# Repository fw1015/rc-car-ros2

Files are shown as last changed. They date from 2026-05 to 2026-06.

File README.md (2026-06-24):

# RC Car ROS2 Project

An autonomous RC car built with **ROS 2 Jazzy**, **Raspberry Pi 5**, and a web-based control interface.





## Features

- **Real-time Web Control** — Control steering and throttle via browser (phone-friendly)
- **Live Camera Streaming** — Stream video from Raspberry Pi Camera Module 3 Wide
- **Multi-Sensor System** — VL53L5CX (ToF) + dual HC-SR04 ultrasonic sensors
- **Field Mode** — Built-in WiFi hotspot for outdoor operation (no home router needed)
- **ROS2 Architecture** — Web Server Node, Brain Node, Sensors Node, Movement Node
- **3D Printed Mounts** — Custom fixtures for Pi, camera, and sensors

## Media & Demo

### Hardware Assembly
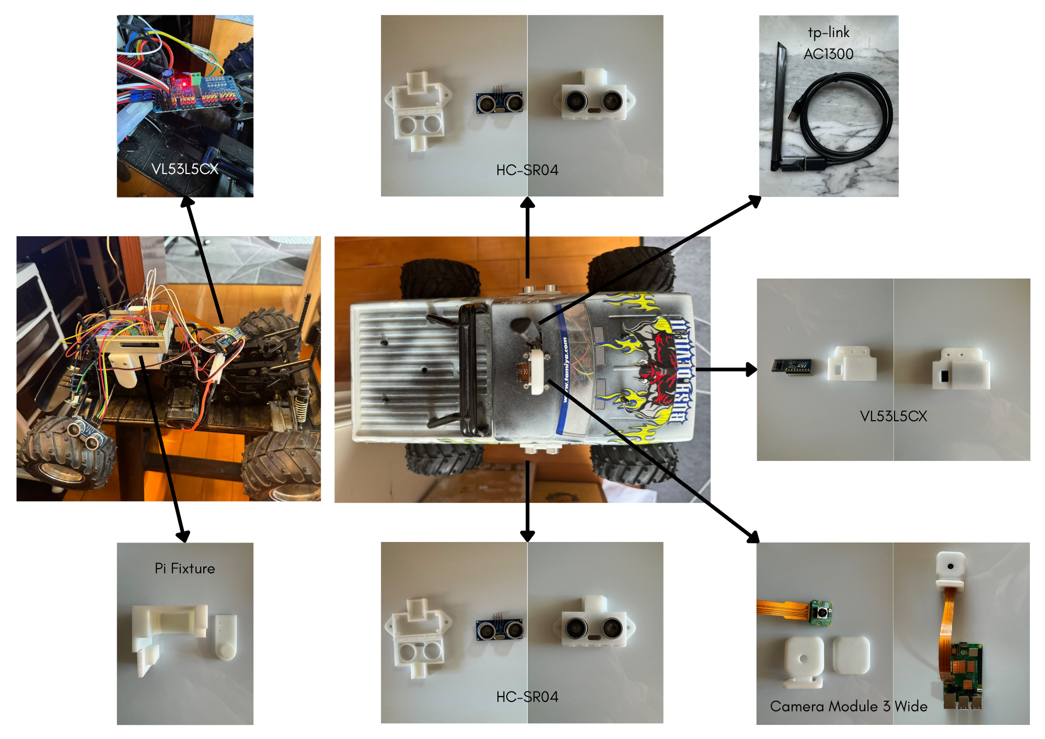
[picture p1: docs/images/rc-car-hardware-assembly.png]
RC Car Hardware Components


### Demo Video
Watch the RC car being controlled in real-time via the web interface:

[▶️ Watch Demo Video](https://github.com/fw1015/rc-car-ros2/releases/download/v1.0/RC.Control.mp4)

---

## Tech Stack

- **ROS 2 Jazzy** (Ubuntu 24.04)
- **Raspberry Pi 5** + Camera Module 3 Wide
- **Python** + Flask (web interface)
- **gpiozero** + LGPIO (hardware control)
- **SolidWorks** (3D design)

## Project Structure

```bash
rc-car-ros2/
├── src/
│   ├── web_interface/            # Flask web server + frontend
│   ├── robot_brain/              # Decision making & safety logic
│   ├── robot_movement/           # Servo and ESC control nodes
│   ├── robot_sensors/            # ToF + Ultrasonic sensor nodes
│   └── camera_ros/               # Camera streaming node
├── docs/
│   ├── images/                   # Hardware photos and diagrams
│   └── hardware_architecture.md  # Hardware mapping and pin connections
├── hardware/
│   └── 3d_models/                # STL files for 3D printed parts
├── .gitignore
└── README.md

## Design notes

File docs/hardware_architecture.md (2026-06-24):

# Hardware Architecture & Node Mapping

This document outlines the hardware components, their corresponding ROS 2 nodes, and the physical wiring architecture of the autonomous RC vehicle.

## Node Overview

| Node | Hardware? | Model | Placement | Publish | Subscribe | Message Type | Service/Client |
|---|---|---|---|---|---|---|---|
| `robot_brain_node` | N | NA | NA | `/cmd_vel` | `/tof/distance`, `/cmd_vel_raw` | `Twist`, `Float64` | Client to `i2c_manager` |
| `tof_sensor_node` | Y | VL53L5CX | Front | `/tof/distance` | - | `Float64` | - |
| `us_sensor_node (L)`  | Y | HC-SR04 | Left | `/left_distance` | - | `Range` | - |
| `us_sensor_node (R)`  | Y | HC-SR04 | Right | `/right_distance` | - | `Range` | - |
| `i2c_manager` | Y | PCA9685 + QUICRUN-1060 | Mid | - | - | - | Service (`set_esc`) |
| `web_server_node` | N | NA | NA | `/cmd_vel_raw` | `/tof/distance`, `/left_distance`, `/right_distance` | `Twist` | - |

---

## Hardware Components

### USB WiFi Adapter (TP-Link Archer T3U Plus)

- **Model**: TP-Link Archer T3U Plus (AC1300)
- **Purpose**: Provides stable, longer-range WiFi connectivity for outdoor operation and reliable live camera streaming.
- **Connection Type**: USB 3.0 (plugged into Raspberry Pi 5 USB port)
- **Usage**:
  - Acts as WiFi **client** when connecting to a phone hotspot in Field Mode.
  - Improves stability and range compared to the built-in Raspberry Pi WiFi, especially outdoors.
- **Power Consumption**: ~500–900mA under load (powered directly from Pi USB 3.0 port).
- **Notes**: 
  - Used primarily to maintain a stable connection for camera streaming when operating away from home WiFi.
  - Helps reduce latency and dropouts during outdoor testing.

### VL53L5CX (ToF Sensor)
- **PIN 1 (3V3 Power)**: LPn, PWREN, AVDD, IOVDD
- **PIN 3 (GPIO 2)**: SDA
- **PIN 5 (GPIO 3)**: SCL
- **PIN 9 (GND)**: GND

### HC-SR04 (Left Ultrasonic)
- **PIN 2 (5V Power)**: VCC
- **PIN 9 (GND)**: GND
- **PIN 13 (GPIO 27)**: Trig
- **PIN 15 (GPIO 22)**: Echo

### HC-SR04 (Right Ultrasonic)
- **PIN 4 (5V Power)**: VCC
- **PIN 9 (GND)**: GND
- **PIN 16 (GPIO 23)**: Trig
- **PIN 18 (GPIO 24)**: Echo

### PCA9685 (I2C Motor Manager)
- **PIN 17 (3V3 Power)**: VCC (logic)
- **PIN 34 & 39 (GND)**: GND + OE
- **Channel 0**: QUICRUN-1060 ESC (Throttle)
- **Channel 2**: Futaba S3003 Servo (Steering)

---

## Power Architecture

- **Main Battery (7.2V NiMH)**: Powers the ESC directly.
- **ESC Built-in BEC (6V/3A)**: Powers the PCA9685 V+ rail → Futaba S3003 steering servo.
- **Pi 5V Rail**: Powers the Raspberry Pi, **TP-Link Archer T3U Plus**, Camera Module 3, and both HC-SR04 sensors.
- **Pi 3.3V Rail**: Powers the VL53L5CX ToF sensor and PCA9685 logic (VCC).
- **Common Ground**: All components share a common ground to ensure signal integrity.

**Note on USB WiFi Adapter**: The TP-Link Archer T3U Plus draws power from the Pi’s USB 3.0 port. While the Pi 5 can generally handle it, high camera streaming load + USB WiFi may increase total current draw. Monitor thermals during long outdoor sessions.

---

## Notes

- HC-SR04 Echo pins use a voltage divider (1kΩ + 1kΩ) to safely step down 5V signals to 3.3V logic levels.
- The **TP-Link Archer T3U Plus** was added specifically to improve WiFi stability and camera streaming performance when operating outdoors in Field Mode.
- The Camera Module 3 uses the official CSI port to avoid USB bandwidth contention with the WiFi adapter.
- The PCA9685 provides electrical isolation between the Pi’s 3.3V logic and the higher voltage servo/ESC power rail.

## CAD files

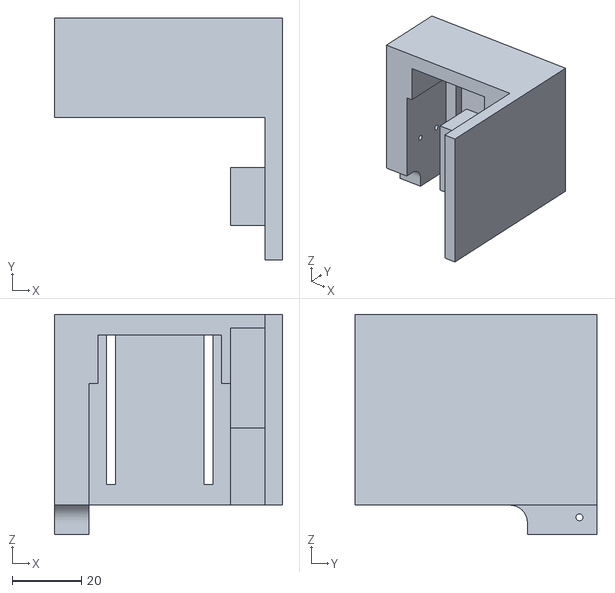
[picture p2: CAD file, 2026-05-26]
hardware/3d_models/PI_Fixture_Main.STL
65.7 x 69.6 x 63.5

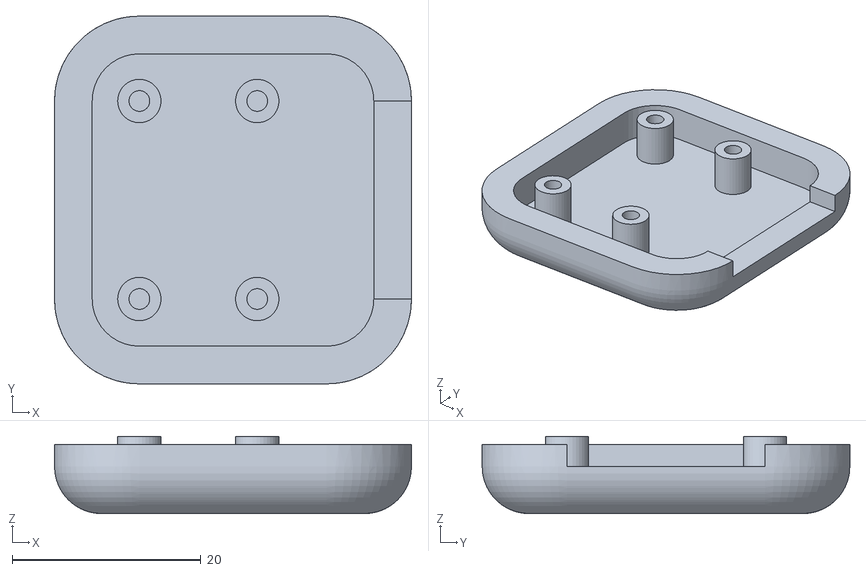
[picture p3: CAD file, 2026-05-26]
hardware/3d_models/Cam_Fixture_Front.STL
37.9 x 39.0 x 8.20

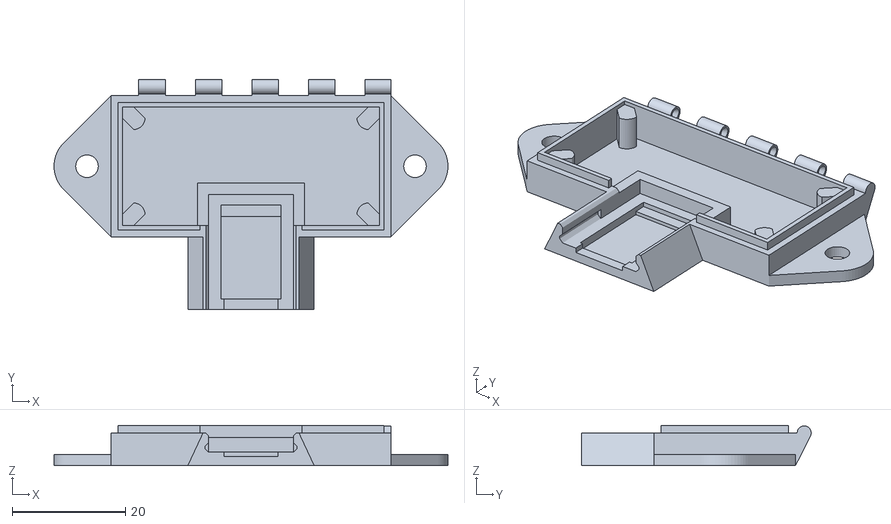
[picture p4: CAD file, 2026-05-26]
hardware/3d_models/HC-SR04_Fixture_Bottom.stl
69.7 x 40.6 x 7.15

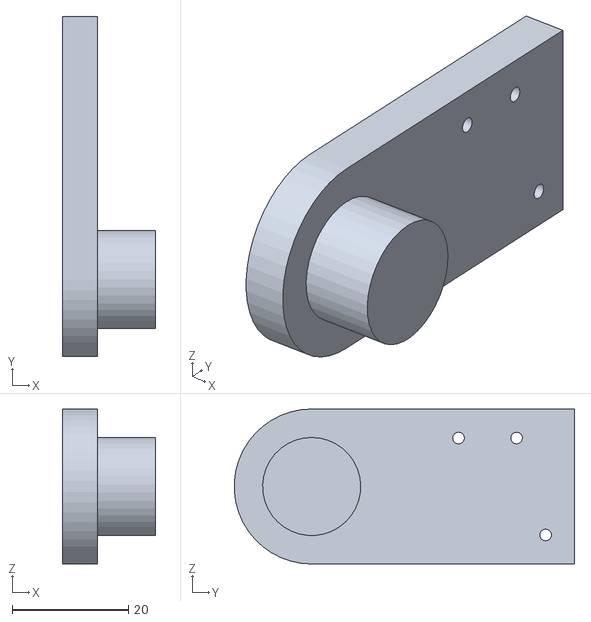
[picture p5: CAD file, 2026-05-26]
hardware/3d_models/PI_Fixture_Sub.STL
16.0 x 58.6 x 26.7

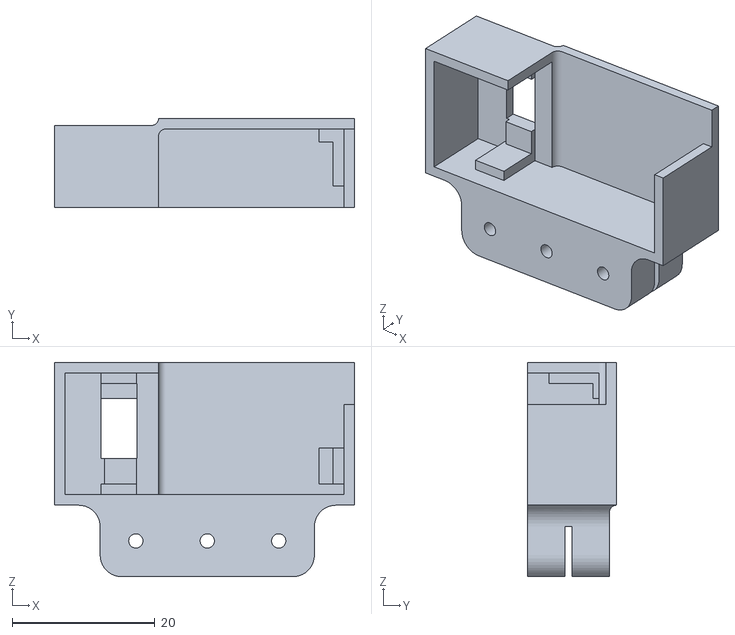
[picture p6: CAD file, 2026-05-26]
hardware/3d_models/Tof_Fixture.STL
42.0 x 12.5 x 30.0

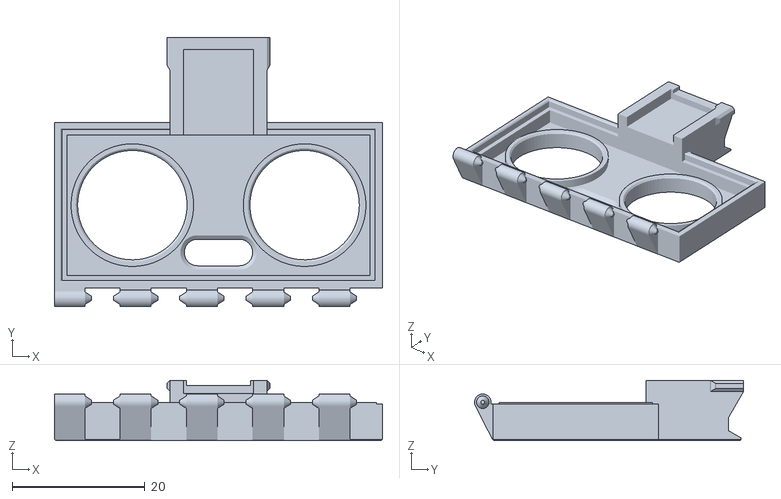
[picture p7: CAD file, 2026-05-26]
hardware/3d_models/HC-SR04_Fixture_Top.stl
49.5 x 40.6 x 9.10

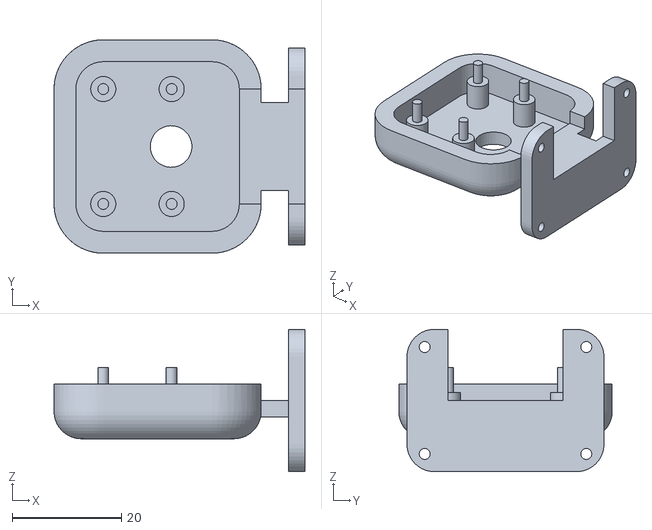
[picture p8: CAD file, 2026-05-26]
hardware/3d_models/Cam_Fixture_Back.STL
45.9 x 39.0 x 26.0

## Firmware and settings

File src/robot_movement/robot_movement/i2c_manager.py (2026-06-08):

#!/usr/bin/env python3

import rclpy
from rclpy.node import Node
from rclpy.executors import MultiThreadedExecutor
import time
from adafruit_extended_bus import ExtendedI2C as I2C
from adafruit_pca9685 import PCA9685 

# Note: We completely removed the ToF / GetDistance imports!
from robot_movement.srv import SetESCServo

class I2CManager(Node):
    """
    Dedicated Motor Controller Node
    
    Handles the PCA9685 PWM driver over I2C to control the ESC (Throttle) 
    and Servo (Steering) via ROS 2 service calls
    """

    def __init__(self):
        super().__init__('i2c_manager')
        
        self.get_logger().info("Starting I2C Manager (Motor Control Only)...")

        # Initialize I2C Bus 2
        self.i2c_esc = I2C(2)
        time.sleep(0.5)

        # Initialize ROS 2 Service before hardware to prevent missing-service warnings
        self.create_service(SetESCServo, 'set_esc_servo', self.set_esc_servo_callback)

        # PCA9685 Hardware State
        self.pca = None
        self.esc_initialized = False

        # Hardware connection retry loop (executes every 2 seconds until powered)
        # This allows the system to start up even if the ESC power is delayed (as it needs to be turned on manually)
        self.esc_retry_timer = self.create_timer(2.0, self.try_init_esc_servo)
        self.get_logger().info("I2C Manager started. Waiting for ESC power if needed.")

    def _set_pwm_pulse(self, channel, pulse_us):
        """
        Safely converts a microsecond pulse into a 16-bit hardware duty cycle
        
        Args:
            channel (int): The PCA9685 channel (0-15)
            pulse_us (float): The desired PWM pulse width in microseconds
        """
        if self.pca is None:
            return
            
        # Hardware safety clamp - Prevent sending signals outside standard RC limits
        pulse_us = max(900, min(2100, pulse_us))
        
        # Convert microsecond pulse to 16-bit duty cycle at 50Hz (20,000us period)
        duty = int((pulse_us / 20000) * 65535)
        self.pca.channels[channel].duty_cycle = duty

    def try_init_esc_servo(self):
        """Attempts to connect to the PCA9685 and arm the motors"""
        if self.esc_initialized:
            return
            
        try:
            # Initialize chip
            self.pca = PCA9685(self.i2c_esc)
            self.pca.frequency = 50  # 50Hz for standard RC equipment
            
            # CHANNEL 0: Arm the ESC (1500us Neutral)
            self._set_pwm_pulse(0, 1500) # Neutral 1500us
            
            # CHANNEL 2: Center the Steering Servo (1500us Neutral)
            self._set_pwm_pulse(2, 1500) # Center 1500us
            
            self.esc_initialized = True
            self.get_logger().info("✅ PCA9685 initialized: ESC Armed & Wheels Centered!")
            
            # Terminate the retry loop upon successful connection
            self.esc_retry_timer.cancel()
            
        except Exception as e:
            self.get_logger().warn(f"PCA9685 not ready yet: {e}")

    def set_esc_servo_callback(self, request, response):
        """
        Service callback to actuate physical hardware
        Maps incoming float values (-1.0 to 1.0) to physical PWM microseconds
        """
        if not self.esc_initialized or self.pca is None:
            response.success = False
            response.message = "PCA9685 not powered on yet"
            return response
            
        try:
            channel = request.channel
            value = request.value  # Value arrives as -1.0 to 1.0
            
            if channel == 0:
                # CHANNEL 0: ESC (Throttle)
                # Mapping: -1.0 -> 1000us | 0.0 -> 1500us | 1.0 -> 2000us
                pulse = 1500 + (value * 500)
                self._set_pwm_pulse(0, pulse)
                response.message = f"ESC throttle set to {value:.2f} ({pulse}us)"
                
            elif channel == 2:
                # CHANNEL 2: STEERING SERVO
                # Mapping: -1.0 -> 900us | 0.0 -> 1500us | 1.0 -> 2100us
                pulse = 1500 + (value * 600)
                self._set_pwm_pulse(2, pulse)
                response.message = f"Servo steering set to {value:.2f} ({pulse}us)"
            
            response.success = True
            
        except Exception as e:
            response.success = False
            response.message = str(e)
            
        return response


def main():
    rclpy.init()
    node = I2CManager()
    
    # Utilizing MultiThreadedExecutor to maintain high responsiveness for service calls
    executor = MultiThreadedExecutor()
    executor.add_node(node)
    
    try:
        executor.spin()
    except KeyboardInterrupt:
        pass
    finally:
        node.destroy_node()
        rclpy.shutdown()

if __name__ == '__main__':
    main()

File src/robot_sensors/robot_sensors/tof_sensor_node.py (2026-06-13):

#!/usr/bin/env python3

import rclpy
from rclpy.node import Node
from std_msgs.msg import Float64
import vl53l5cx_ctypes as vl53l5cx

class TofSensorPublisher(Node):
    """
    Hardware driver node for the VL53L5CX Time-of-Flight sensor
    
    Responsibilities:
    - Initializes the I2C ToF sensor in 4x4 grid resolution mode
    - Polls the hardware synchronously at 10Hz
    - Applies spatial clustering (neighbor check) to the center 4 zones to filter noise
    - Publishes the final reliable distance in meters to the `/tof/distance` topic
    """

    def __init__(self):
        super().__init__('tof_sensor_node')

        self.publisher = self.create_publisher(Float64, '/tof/distance', 10)
        
        # Hardware State
        self.tof = None
        self.init_tof_sensor()

        # Timer to read the sensor at 10 Hz
        self.timer = self.create_timer(0.1, self.timer_callback)

        self.get_logger().info('ToF Sensor Node started (Standalone)')

    def init_tof_sensor(self):
        """Attempts to initialize the VL53L5CX sensor over I2C"""
        try:
            self.tof = vl53l5cx.VL53L5CX()
            self.tof.set_resolution(4*4)
            self.tof.set_ranging_frequency_hz(10)
            self.tof.start_ranging()
            self.get_logger().info("✅ VL53L5CX initialized successfully")
        except Exception as e:
            self.get_logger().error(f"Failed to init ToF sensor: {e}")
            self.tof = None

    def timer_callback(self):
        """Main sensor polling loop. Creates a horizontal 'letterbox' field of view 
        to ignore ground/bumper reflections while detecting wide or thin forward obstacles."""
        
        # Publish safe default (4.0m) if the sensor hardware is dead or disconnected
        if self.tof is None:
            msg = Float64()
            msg.data = 4.0
            self.publisher.publish(msg)
            return

        try:
            if self.tof.data_ready():
                data = self.tof.get_data()
                distances = list(data.distance_mm[0])
                statuses = list(data.target_status[0])

                # --- TEMPORARY DEBUG VISUALIZER ---
                
                grid = [distances[i:i+4] for i in range(0, 16, 4)]
                stat_grid = [statuses[i:i+4] for i in range(0, 16, 4)]
                self.get_logger().info(
                    f"\nDISTANCES:\nRow 1 [4-7]:   {grid[1]}\n"
                    f"STATUSES:\nRow 1 [4-7]:   {stat_grid[1]}\n------------------------"
                )
                # ----------------------------------
                # ----------------------------------
                
                # 1. NARROW HORIZONTAL FOV (The "Blinders")
                horizon_zones = [5, 6]
                valid_obstacle_dists = []

                # 2. Extract valid distances (Relaxed for Outdoors)
                for i in horizon_zones:
                    # 5 & 9 = Perfect valid reading
                    # 6, 10, 12 = Warning readings (Extremely common outdoors due to sunlight IR interference)
                    if statuses[i] in (5, 6, 9, 10, 12) and distances[i] > 0:
                        valid_obstacle_dists.append(distances[i])

                # 3. Calculate Final Safe Distance and Publish
                msg = Float64()
                if valid_obstacle_dists:
                    msg.data = min(valid_obstacle_dists) / 1000.0
                else:
                    msg.data = 4.0
                    
                self.publisher.publish(msg)

        except Exception as e:
            self.get_logger().warning(f"Error reading ToF: {e}")
            # Failsafe on I/O error
            msg = Float64()
            msg.data = 4.0
            self.publisher.publish(msg)


def main(args=None):
    rclpy.init(args=args)
    node = TofSensorPublisher()
    
    try:
        rclpy.spin(node)
    except KeyboardInterrupt:
        pass
    finally:
        node.destroy_node()
        rclpy.shutdown()

if __name__ == '__main__':
    main()

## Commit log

2026-05-26 Readme changes, Hardware directory organise
    [Cam_Fixture_Back.STL, Cam_Fixture_Front.STL, HC-SR04_Fixture_Bottom.stl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]
2026-06-07 Refactor: Major architecture upgrade and codebase professionalization
    - Replaced direct GPIO motor control with I2C PCA9685 manager node.
    - Implemented spatial clustering and temporal median filters for ToF and Ultrasonic nodes to eliminate hardware noise.
    - Decoupled left/right ultrasonic publishing to prevent single-sensor failure states.
    - Migrated Flask web server to a background daemon thread to prevent ROS 2 blocking.
    - Standardized entire Python backend with strict type hinting and PEP 8 docstrings.
    - Applied JSDoc standard comments to frontend teleoperation logic.
    - Updated hardware_architecture.md to reflect new I2C power routing.
    [i2c_manager.py, tof_sensor_node.py, ultrasound_sensor_node.py]
2026-06-08 Add speed governor to the web UI. Add brake safety logic.
2026-06-15 PID Control real time on web interface
2026-06-24 docs: Add hardware assembly photo + fix .gitignore
